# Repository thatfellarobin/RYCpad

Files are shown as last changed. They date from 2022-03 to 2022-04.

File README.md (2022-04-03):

# RYCpad
[][cc-by-nc-sa]

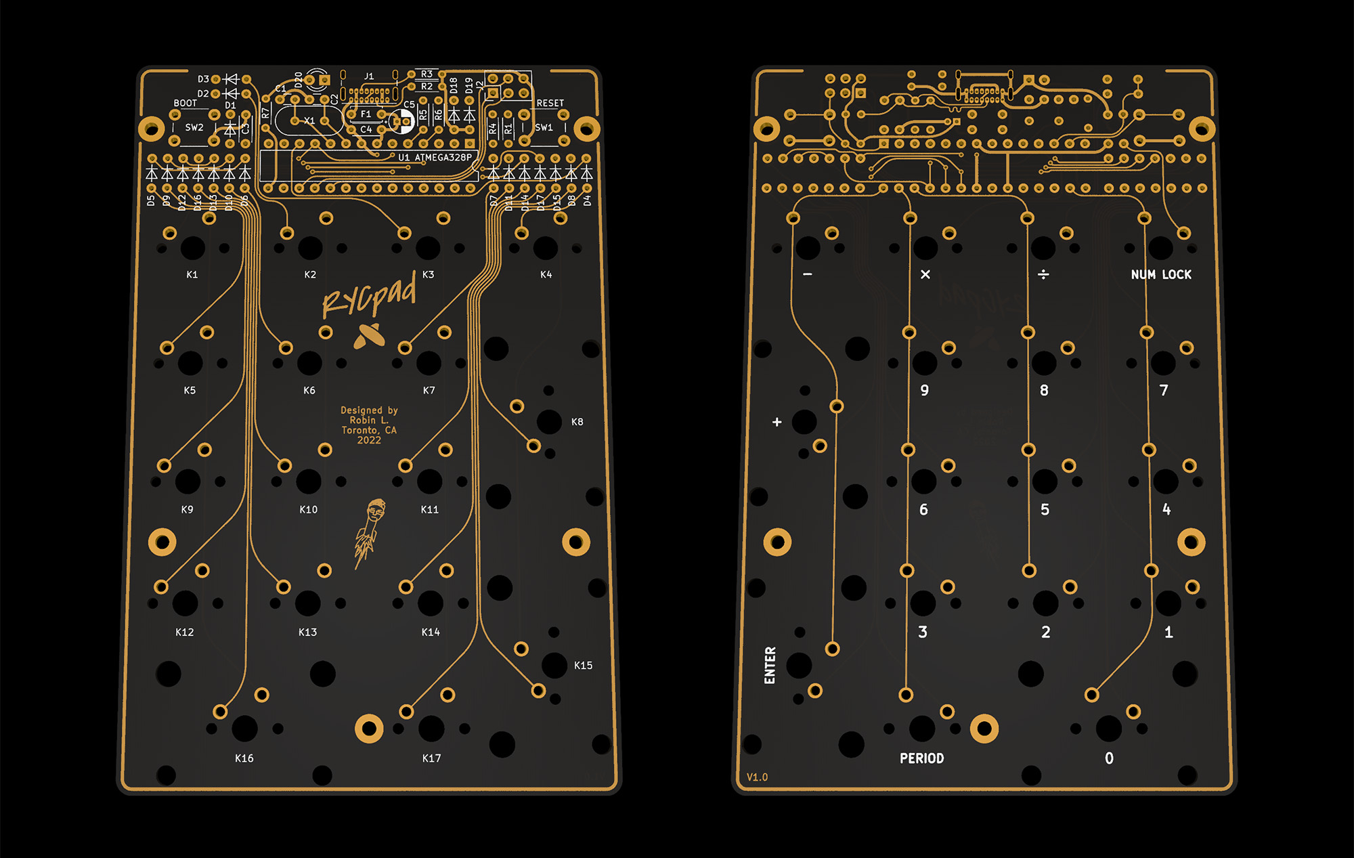
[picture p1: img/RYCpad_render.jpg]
Render

**RYCpad rendered**

RYCpad (pronounced "ricey pad") is a custom mechanical keyboard numpad with through-hole components. It follows my other project [Axon](https://github.com/thatfellarobin/axon) in its emphasis on symmetric layout. RYCpad runs on an ATmega328P using VUSB and QMK.

RYCpad is designed to be printed with a black substrate PCB and clear solder mask, such as [OSHpark's After Dark service](https://docs.oshpark.com/services/afterdark/). There are no ground planes, allowing the traces to stand out. The plate and bottom PCB have windows in the solder mask to achieve a similar effect without the need for transparent solder mask.

### Resources and Config
The `.svg` file for laser-cutting an acrylic cover for the components can be found in `doc/`. For other materials, a `.dxf` is provided.

The `.svg` file for laser-cutting an acrylic rear plate is also provided in `doc/`. The rear plate is intended to be produced using transparent acrylic, to show off the main PCB. However, a rear plate "PCB" is provided.

A switch plate "PCB" is provided, but a `.dxf` can also be found in `doc/` for those who want to make it from a different material.

⚡⚠️ **Note:** `.svg` files account for a laser kerf of 0.2 mm, but the `.dxf` files do not account for any kerf. `.svg` files use green for cut lines, and blue for engraving.

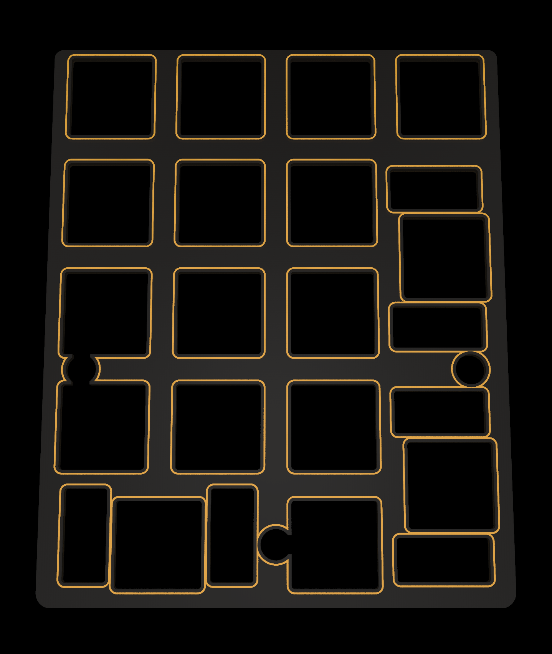
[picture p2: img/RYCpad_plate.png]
\
**RYCpad switch plate "PCB"**

The indicator LED is controlled using [QMK's backlight feature](https://github.com/qmk/qmk_firmware/blob/master/docs/feature_backlight.md), which enables hardware PWM dimming in case you find the LED too bright.

### Component Libraries

**Symbols:**
- [Keyboard symbols by Hasu](https://github.com/tmk/kicad_lib_tmk)

**Footprints:**
- [Keyswitches by Daprice](https://github.com/daprice/keyswitches.pretty), but modified for my own tastes/uses.
- My own footprints for mostly decorative things. Can be found in `lib/`

## License
This work is licensed under a
[Creative Commons Attribution-NonCommercial-ShareAlike 4.0 International License][cc-by-nc-sa].

[][cc-by-nc-sa]

[cc-by-nc-sa]: http://creativecommons.org/licenses/by-nc-sa/4.0/
[cc-by-nc-sa-image]: https://licensebuttons.net/l/by-nc-sa/4.0/88x31.png
[cc-by-nc-sa-shield]: https://img.shields.io/badge/License-CC%20BY--NC--SA%204.0-lightgrey.svg

If you have built upon this project and have significantly altered the design, the non-commercial clause can be waived with explicit permission.

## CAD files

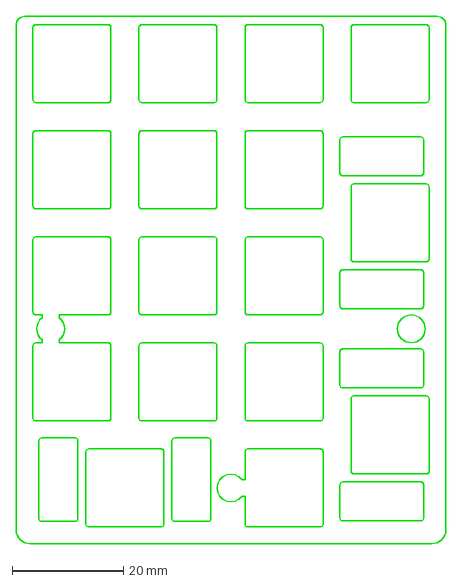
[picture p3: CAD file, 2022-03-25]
doc/plate_basic.dxf
77.2 x 94.7 mm

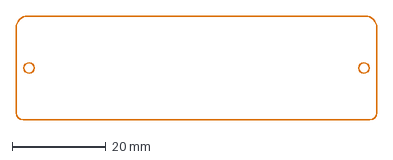
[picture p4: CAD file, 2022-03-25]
doc/component_cover.dxf
77.2 x 22.2 mm

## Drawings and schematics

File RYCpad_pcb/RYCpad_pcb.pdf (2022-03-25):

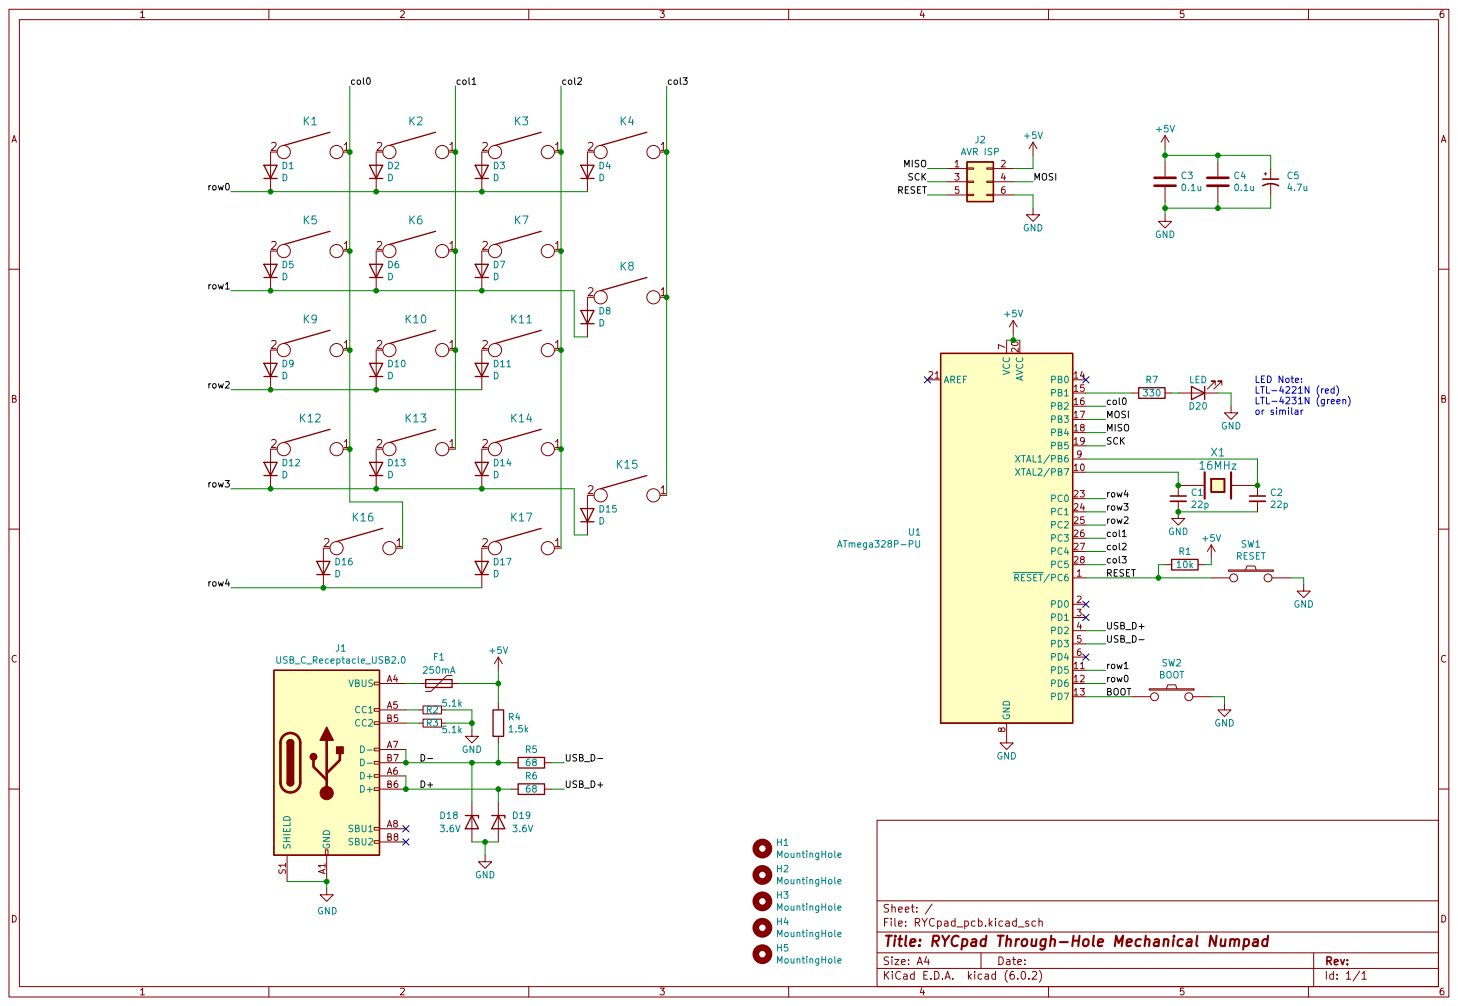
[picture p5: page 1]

LED Note: LTL-4221N (red)

LTL-4231N (green) or similar

Id: 1/1 Title: RYCpad Through-Hole Mechanical Numpad

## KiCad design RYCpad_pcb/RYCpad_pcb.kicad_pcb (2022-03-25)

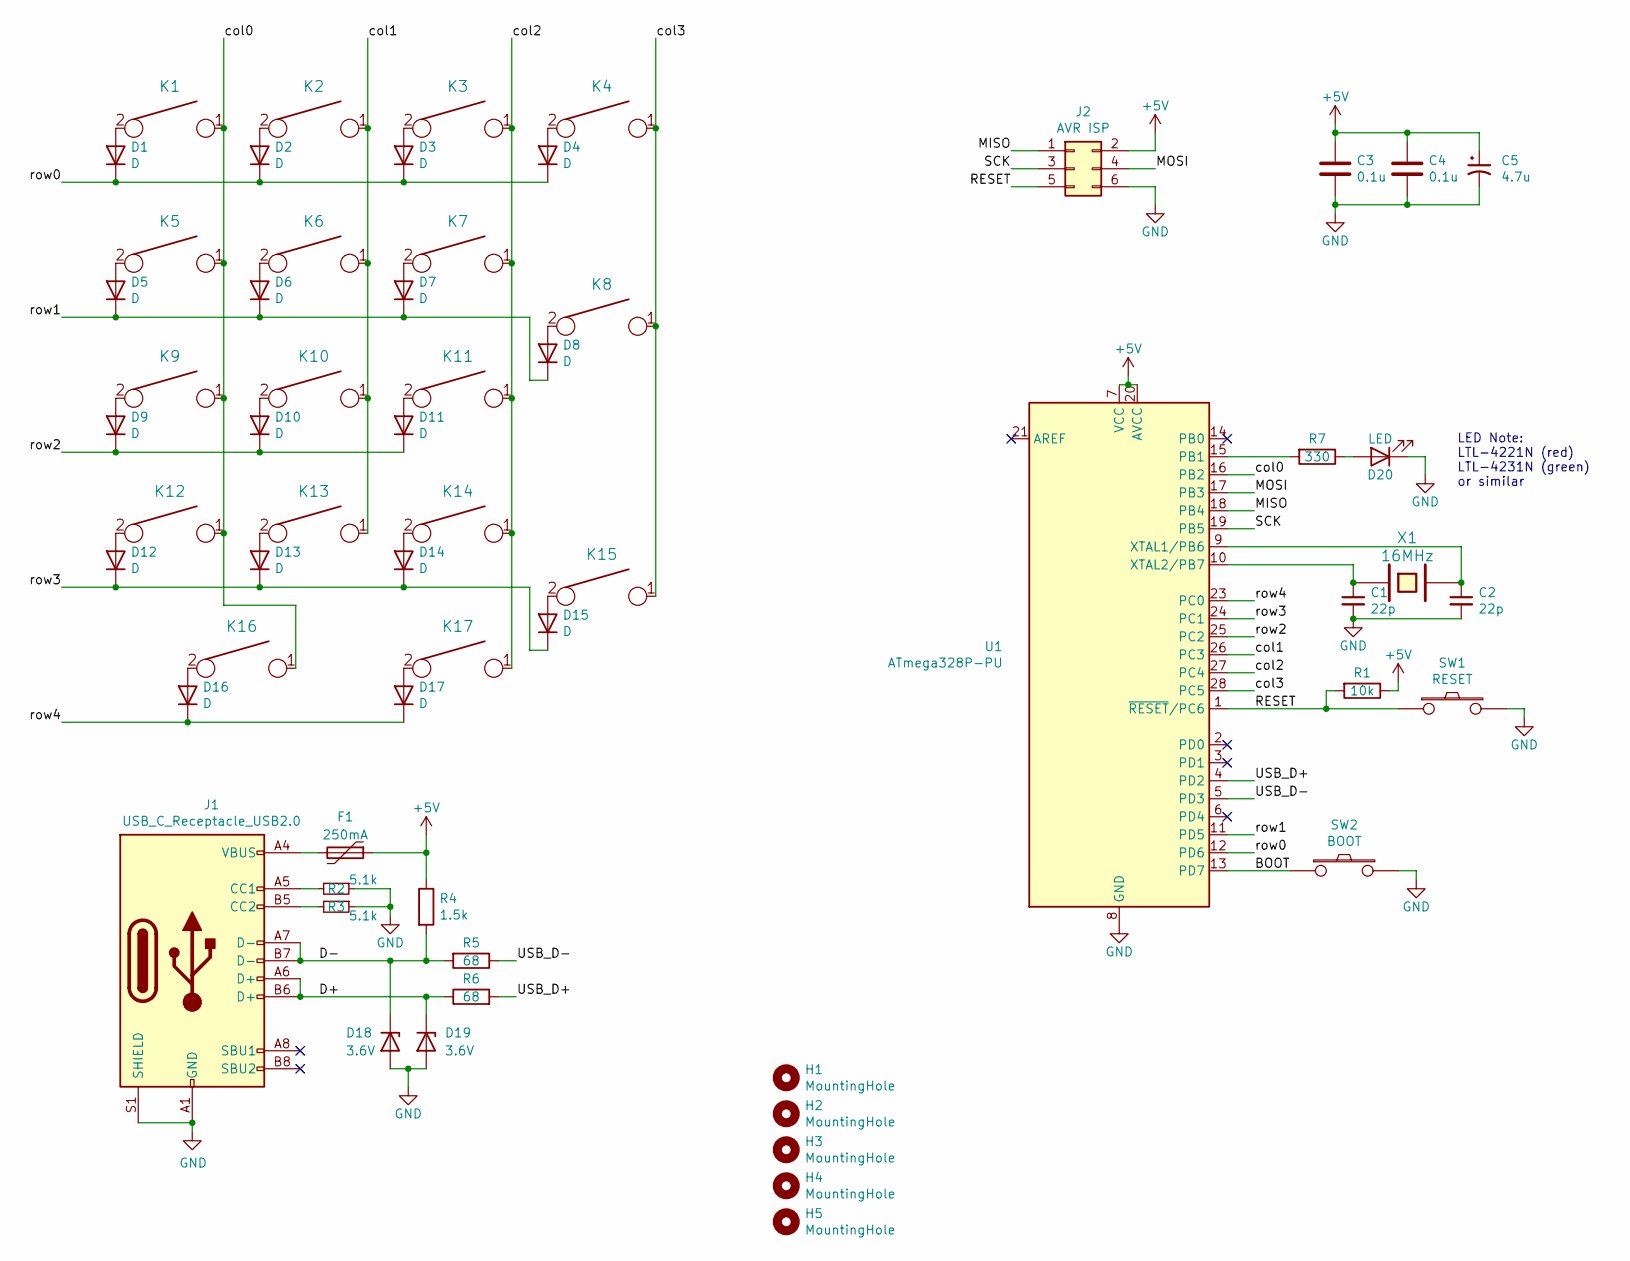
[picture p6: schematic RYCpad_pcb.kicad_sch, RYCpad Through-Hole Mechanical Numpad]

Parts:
C1, C2: 22p; C_Disc_D3.0mm_W1.6mm_P2.50mm
C3, C4: 0.1u; C_Disc_D4.3mm_W1.9mm_P5.00mm
C5: 4.7u; CP_Radial_D4.0mm_P1.50mm
D1, D2, D3, D4, D5, D6, D7, D8, D9, D10, D11, D12, D13, D14, D15, D16, D17: D; D_DO-35_SOD27_P5mm_Horizontal
D18, D19: 3.6V; D_DO-35_SOD27_P5mm_Horizontal
D20: LED; LED_D3.0mm
F1: 250mA; C_Disc_D5.0mm_W2.5mm_P5.00mm
H1, H2, H3, H4, H5: MountingHole; MountingHole_2.2mm_M2_Pad
J1: USB_C_Receptacle_USB2.0; USB_C_Receptacle_GCT_USB4085_personalized
J2: AVR ISP; PinHeader_2x03_P2.54mm_Vertical
K1, K2, K3, K4, K5, K6, K7, K8, K9, K10, K11, K12, K13, K14, K15, K16, K17: KEYSW; SW_MX_NoBorderSilk
R1: 10k; R_Axial_DIN0204_L3.6mm_D1.6mm_P5.08mm_Horizontal
R2, R3: 5.1k; R_Axial_DIN0204_L3.6mm_D1.6mm_P5.08mm_Horizontal
R4: 1.5k; R_Axial_DIN0204_L3.6mm_D1.6mm_P5.08mm_Horizontal
R5, R6: 68; R_Axial_DIN0204_L3.6mm_D1.6mm_P5.08mm_Horizontal
R7: 330; R_Axial_DIN0204_L3.6mm_D1.6mm_P5.08mm_Horizontal
SW1: RESET; SW_PUSH_6mm
SW2: BOOT; SW_PUSH_6mm
U1: ATmega328P-PU; DIP-28_W7.62mm
X1: 16MHz; Crystal_HC49-U_Vertical

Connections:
+5V: C3.1, C4.1, C5.1, F1.1, J2.2, R1.1, R4.1, U1.7 (VCC), U1.20 (AVCC)
/BOOT: SW2.1, U1.13 (PD7)
/D+: D19.1 (K), J1.A6 (D+), J1.B6 (D+), R6.1
/D-: D18.1 (K), J1.A7 (D-), J1.B7 (D-), R4.2, R5.2
/MISO: J2.1, U1.18 (PB4)
/MOSI: J2.4, U1.17 (PB3)
/RESET: J2.5, R1.2, SW1.1, U1.1 (~RESET/PC6)
/SCK: J2.3, U1.19 (PB5)
/USB_D+: R6.2, U1.4 (PD2)
/USB_D-: R5.1, U1.5 (PD3)
/col0: K1.1, K5.1, K9.1, K12.1, K16.1, U1.16 (PB2)
/col1: K2.1, K6.1, K10.1, K13.1, U1.26 (PC3)
/col2: K3.1, K7.1, K11.1, K14.1, K17.1, U1.27 (PC4)
/col3: K4.1, K8.1, K15.1, U1.28 (PC5)
/row0: D1.1 (K), D2.1 (K), D3.1 (K), D4.1 (K), U1.12 (PD6)
/row1: D5.1 (K), D6.1 (K), D7.1 (K), D8.1 (K), U1.11 (PD5)
/row2: D9.1 (K), D10.1 (K), D11.1 (K), U1.25 (PC2)
/row3: D12.1 (K), D13.1 (K), D14.1 (K), D15.1 (K), U1.24 (PC1)
/row4: D16.1 (K), D17.1 (K), U1.23 (PC0)
GND: C1.2, C2.2, C3.2, C4.2, C5.2, D18.2 (A), D19.2 (A), D20.1 (K), J1.A1 (GND), J1.A12 (GND), J1.B1 (GND), J1.B12 (GND), J1.S1 (SHIELD), J2.6, R2.1, R3.1, SW1.2, SW2.2, U1.8 (GND), U1.22 (GND)
unnamed: C1.1, U1.10 (XTAL2/PB7), X1.1
unnamed: C2.1, U1.9 (XTAL1/PB6), X1.2
unnamed: D1.2 (A), K1.2
unnamed: D2.2 (A), K2.2
unnamed: D3.2 (A), K3.2
unnamed: D4.2 (A), K4.2
unnamed: D5.2 (A), K5.2
unnamed: D6.2 (A), K6.2
unnamed: D7.2 (A), K7.2
unnamed: D8.2 (A), K8.2
unnamed: D9.2 (A), K9.2
unnamed: D10.2 (A), K10.2
unnamed: D11.2 (A), K11.2
unnamed: D12.2 (A), K12.2
unnamed: D13.2 (A), K13.2
unnamed: D14.2 (A), K14.2
unnamed: D15.2 (A), K15.2
unnamed: D16.2 (A), K16.2
unnamed: D17.2 (A), K17.2
unnamed: D20.2 (A), R7.1
unnamed: F1.2, J1.A4 (VBUS), J1.A9 (VBUS), J1.B4 (VBUS), J1.B9 (VBUS)
unnamed: J1.A5 (CC1), R2.2
unnamed: J1.B5 (CC2), R3.2
unnamed: R7.2, U1.15 (PB1)

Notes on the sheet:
LED Note: LTL-4221N (red) LTL-4231N (green) or similar

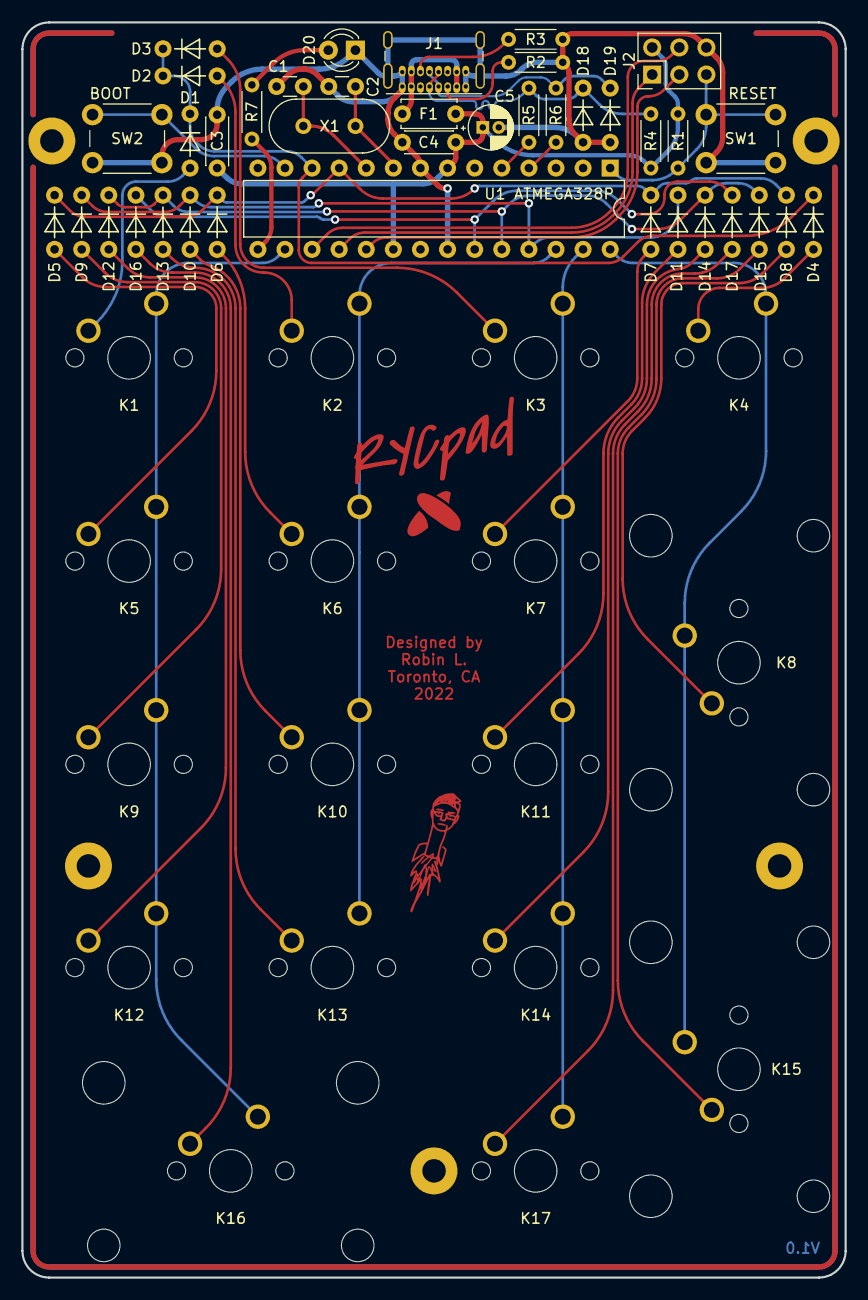
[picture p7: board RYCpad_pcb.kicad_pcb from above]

Board: 2 copper layers, 77.2 x 117.6 mm, 63 parts (1 on the bottom side), 44 nets.

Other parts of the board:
svg2mod, svg2mod#2: G***; RYCpad_coppertrim_cut

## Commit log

2022-03-11 Rename and fix PCB
    - Renamed files from 'ricey' to RYC
    - Fixed PCB to have all intact connections
    [RYCpad_pcb-B_Cu.gbl, RYCpad_pcb-B_Mask.gbs, RYCpad_pcb-B_Paste.gbp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]
2022-03-12 add intended PCB fabrication process to README
2022-03-12 Add logo art
    - also, numerous small routing changes
    [RYCpad_pcb.kicad_pcb]
2022-03-12 update rear pcb
    [RYCpad_pcb_rear.kicad_pcb]
2022-03-12 minor routing changes
    [RYCpad_pcb.kicad_pcb]
2022-03-12 minor routing changes
    - also, untrack gerbers
    [RYCpad_pcb-B_Cu.gbl, RYCpad_pcb-B_Mask.gbs, RYCpad_pcb-B_Paste.gbp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]
2022-03-12 Make LED software-controlled
    [RYCpad_pcb.kicad_pcb, RYCpad_pcb.kicad_sch]
2022-03-12 update MCU silkscreen placement
    [RYCpad_pcb.kicad_pcb]
2022-03-12 add rice icon
    [RYCpad_pcb.kicad_pcb]
2022-03-12 rounded all traces
    [RYCpad_pcb.kicad_pcb]
2022-03-12 adjust credits
    [RYCpad_pcb.kicad_pcb]
2022-03-12 add component cover cutpath dxf
    [component_cover.dxf]
2022-03-12 add laser cut outline to PCB file
    - also, a note in the readme regarding laser kerf
    [RYCpad_pcb.kicad_pcb]
2022-03-13 added copper trim
    [RYCpad_pcb.kicad_pcb]
2022-03-13 add version number to pcb
    [RYCpad_pcb.kicad_pcb]
2022-03-14 connected shield through RC filter
    [RYCpad_pcb.kicad_pcb, RYCpad_pcb.kicad_sch]
2022-03-14 thickened power traces
    [RYCpad_pcb.kicad_pcb]
2022-03-14 aesthetic changes
    - Changed diode footprint to use prettier diode symbol
    - Minor layout adjustments
    - render update to follow in later commit
    [RYCpad_pcb.kicad_pcb]
2022-03-15 new render
    - also, minor routing changes
    [RYCpad_pcb.kicad_pcb]
2022-03-17 minor changes
    - update rear pcb
    - thinner silkscreen lines on diode footprint
    [RYCpad_pcb.kicad_pcb, RYCpad_pcb_rear.kicad_pcb]
2022-03-18 USB dataline symmetry
    [RYCpad_pcb.kicad_pcb]
2022-03-20 add plate file
    [plate_basic.dxf]
2022-03-20 matched USB data line length
    [RYCpad_pcb.kicad_pcb, RYCpad_pcb.kicad_sch]
2022-03-20 revise usb shield strategy
    - now shorted to ground
    [RYCpad_pcb.kicad_pcb, RYCpad_pcb.kicad_sch]
2022-03-20 ground trace thickness fix
    [RYCpad_pcb.kicad_pcb]
2022-03-21 update rear pcb
    - Add solder mask windows to allow copper to show even at cheaper board
    shops
    - Add copper trim around the edge of the rear pcb
    [RYCpad_pcb_rear.kicad_pcb]
2022-03-21 add pcb plate
    [RYCpad_plate.kicad_pcb, RYCpad_plate.kicad_sch]
2022-03-21 routing improvements
    - render to follow
    [RYCpad_pcb.kicad_pcb]
2022-03-21 update copper trim
    [RYCpad_pcb.kicad_pcb, RYCpad_pcb_rear.kicad_pcb, RYCpad_plate.kicad_pcb]
2022-03-22 minor routing changes, add suggested led
    [RYCpad_pcb.kicad_pcb, RYCpad_pcb.kicad_sch]
2022-03-22 add candidate gerber for 1.0 final
    [RYCpad_pcb-B_Cu.gbl, RYCpad_pcb-B_Mask.gbs, RYCpad_pcb-B_Silkscreen.gbo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]
2022-03-23 update plate "PCB" and produce gerber
    [RYCpad_plate-B_Cu.gbr, RYCpad_plate-B_Mask.gbr, RYCpad_plate-B_Silkscreen.gbr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]
2022-03-23 update LED pin
    - QMK supports hardware PWM on pin PB1 and PB2 for backlight dimming.
    The hope is that hardware PWM dimming can be exploited for the
    indicator LED, which mitigates any issues related to excessive LED
    brightness.
    [RYCpad_pcb-B_Cu.gbl, RYCpad_pcb-B_Mask.gbs, RYCpad_pcb-B_Silkscreen.gbo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]
2022-03-23 adjust col1 pin
    change col1 pin PB3 >>> PC3
    [RYCpad_pcb-B_Cu.gbl, RYCpad_pcb-B_Mask.gbs, RYCpad_pcb-B_Silkscreen.gbo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]
2022-03-24 add copper pour to plate
    [RYCpad_plate-B_Cu.gbr, RYCpad_plate-B_Mask.gbr, RYCpad_plate-B_Silkscreen.gbr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]
2022-03-24 change LED resistor default value
    [RYCpad_pcb.kicad_pcb, RYCpad_pcb.kicad_sch]
2022-03-24 added more decoration to plate
    [RYCpad_plate-B_Cu.gbr, RYCpad_plate-B_Mask.gbr, RYCpad_plate-B_Silkscreen.gbr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]
2022-03-25 adjusted component cover and plate
    - Old plate geometry would collide with IC socket
    - Component cover lower edge pushed to show bottom edges of components
    more clearly
    - Plate upper edge pushed to eliminate collision with IC socket
    [RYCpad_pcb.kicad_pcb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]
2022-03-25 re-export gerber
    [RYCpad_pcb-B_Cu.gbl, RYCpad_pcb-B_Mask.gbs, RYCpad_pcb-B_Silkscreen.gbo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]
2022-04-03 add rear plate cutfile

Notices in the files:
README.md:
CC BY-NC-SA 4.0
